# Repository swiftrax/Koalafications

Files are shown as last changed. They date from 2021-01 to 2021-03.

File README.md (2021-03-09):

# Koalafications
Built Image
75% Stacked Acrylic Keyboard with an OLED screen. QMK/VIA compatible 

## Hardware

* M3 Hex Spacer 10mm x 8
* M3 Hex Spacer 6mm x 3
* M3 Screw 8mm x 19
* M3 Screw 6mm x 3

## License

This repository is under the [CC0 1.0 Universal License](https://github.com/swiftrax/Nodu/blob/main/LICENSE). If you plan to sell these pcbs, make sure to read it.

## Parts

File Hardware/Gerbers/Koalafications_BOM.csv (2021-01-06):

value | footprint | datasheet | libsource/_lib | libsource/_part | libsource/_description | sheetpath/_names | sheetpath/_tstamps | tstamp | _ref | fields/field/0/_name | fields/field/0/__text
PRTR5V0U2X | Package_TO_SOT_SMD:SOT-143 | https://assets.nexperia.com/documents/data-sheet/PRTR5V0U2X.pdf | Power_Protection | PRTR5V0U2X | Ultra low capacitance double rail-to-rail ESD protection diode, SOT-363 | / | / | 5FDEC976 | ESD1
10µF | Custom_Footprints:C_0603_Annotated | ~ | Device | C_Small | Unpolarized capacitor, small symbol | / | / | 5FF1D678 | C1 | LCSC | C19702
100nF | Custom_Footprints:C_0603_Annotated | ~ | Device | C_Small | Unpolarized capacitor, small symbol | / | / | 5FF238E7 | C2 | LCSC | C14663
100nF | Custom_Footprints:C_0603_Annotated | ~ | Device | C_Small | Unpolarized capacitor, small symbol | / | / | 5FF29C94 | C3 | LCSC | C14663
100nF | Custom_Footprints:C_0603_Annotated | ~ | Device | C_Small | Unpolarized capacitor, small symbol | / | / | 5FF2FFA4 | C4 | LCSC | C14663
OLED | Custom_Footprints:SSD1306_OLED | ~ | Connector | Conn_01x04_Female | Generic connector, single row, 01x04, script generated (kicad-library-utils/schlib/autogen/connector/) | / | / | 600D2EB9 | J1
16MHz | Custom_Footprints:Resonator_3Pin_Annotated | ~ | Device | Resonator_Small | Three pin ceramic resonator, small symbol | / | / | 5FE6EE64 | Y1
RESET | Custom_Footprints:RESET_PADS | ~ | Switch | SW_Push | Push button switch, generic, two pins | / | / | 5FE7FCB3 | SW1
10kΩ | Custom_Footprints:R_0603_Annotated | ~ | Device | R_Small | Resistor, small symbol | / | / | 5FEDF25E | R2 | LCSC | C25804
10kΩ | Custom_Footprints:R_0603_Annotated | ~ | Device | R_Small | Resistor, small symbol | / | / | 5FEEABCC | R1 | LCSC | C25804
1µF | Custom_Footprints:C_0603_Annotated | ~ | Device | C_Small | Unpolarized capacitor, small symbol | / | / | 5FF0CD6B | C5 | LCSC | C15849
D_Small | Diode_SMD:D_0603_1608Metric_Pad1.05x0.95mm_HandSolder | ~ | Device | D_Small | Diode, small symbol | / | / | 5FF7E7FC | D82 | LCSC | C109002
KC_RGHT | MX_Only:MXOnly-1U-NoLED | ~ | Switch | SW_Push | Push button switch, generic, two pins | / | / | 5FF7E7F6 | K_82
D_Small | Diode_SMD:D_0603_1608Metric_Pad1.05x0.95mm_HandSolder | ~ | Device | D_Small | Diode, small symbol | / | / | 5FF7E7F0 | D72 | LCSC | C109002
KC_END | MX_Only:MXOnly-1U-NoLED | ~ | Switch | SW_Push | Push button switch, generic, two pins | / | / | 5FF7E7EA | K_72
D_Small | Diode_SMD:D_0603_1608Metric_Pad1.05x0.95mm_HandSolder | ~ | Device | D_Small | Diode, small symbol | / | / | 5FF7E7E4 | D58 | LCSC | C109002
KC_HOME | MX_Only:MXOnly-1U-NoLED | ~ | Switch | SW_Push | Push button switch, generic, two pins | / | / | 5FF7E7DE | K_58
D_Small | Diode_SMD:D_0603_1608Metric_Pad1.05x0.95mm_HandSolder | ~ | Device | D_Small | Diode, small symbol | / | / | 5FF7E7D8 | D43 | LCSC | C109002
KC_INS | MX_Only:MXOnly-1U-NoLED | ~ | Switch | SW_Push | Push button switch, generic, two pins | / | / | 5FF7E7D2 | K_43
D_Small | Diode_SMD:D_0603_1608Metric_Pad1.05x0.95mm_HandSolder | ~ | Device | D_Small | Diode, small symbol | / | / | 5FF7E7CC | D28 | LCSC | C109002
KC_DEL | MX_Only:MXOnly-1U-NoLED | ~ | Switch | SW_Push | Push button switch, generic, two pins | / | / | 5FF7E7C6 | K_28
D_Small | Diode_SMD:D_0603_1608Metric_Pad1.05x0.95mm_HandSolder | ~ | Device | D_Small | Diode, small symbol | / | / | 5FF7E78B | D57 | LCSC | C109002
KC_BSLS | MX_Only:MXOnly-1U-NoLED | ~ | Switch | SW_Push | Push button switch, generic, two pins | / | / | 5FF7E785 | K_57
D_Small | Diode_SMD:D_0603_1608Metric_Pad1.05x0.95mm_HandSolder | ~ | Device | D_Small | Diode, small symbol | / | / | 5FF7E77F | D42 | LCSC | C109002
KC_BSLS | MX_Only:MXOnly-1.5U-NoLED | ~ | Switch | SW_Push | Push button switch, generic, two pins | / | / | 5FF7E779 | K_42
D_Small | Diode_SMD:D_0603_1608Metric_Pad1.05x0.95mm_HandSolder | ~ | Device | D_Small | Diode, small symbol | / | / | 5FF7E773 | D27 | LCSC | C109002
KC_BSPC | MX_Only:MXOnly-2U-NoLED | ~ | Switch | SW_Push | Push button switch, generic, two pins | / | / | 5FF7E76D | K_27
D_Small | Diode_SMD:D_0603_1608Metric_Pad1.05x0.95mm_HandSolder | ~ | Device | D_Small | Diode, small symbol | / | / | 5FF63CA0 | D81 | LCSC | C109002
KC_DOWN | MX_Only:MXOnly-1U-NoLED | ~ | Switch | SW_Push | Push button switch, generic, two pins | / | / | 5FF63C9A | K_81
D_Small | Diode_SMD:D_0603_1608Metric_Pad1.05x0.95mm_HandSolder | ~ | Device | D_Small | Diode, small symbol | / | / | 5FF63C94 | D71 | LCSC | C109002
KC_UP | MX_Only:MXOnly-1U-NoLED | ~ | Switch | SW_Push | Push button switch, generic, two pins | / | / | 5FF63C8E | K_71
D_Small | Diode_SMD:D_0603_1608Metric_Pad1.05x0.95mm_HandSolder | ~ | Device | D_Small | Diode, small symbol | / | / | 5FF63C88 | D56 | LCSC | C109002
KC_ENT | MX_Only:MXOnly-2.25U-NoLED | ~ | Switch | SW_Push | Push button switch, generic, two pins | / | / | 5FF63C82 | K_56
D_Small | Diode_SMD:D_0603_1608Metric_Pad1.05x0.95mm_HandSolder | ~ | Device | D_Small | Diode, small symbol | / | / | 5FF63C7C | D41 | LCSC | C109002
KC_RBRC | MX_Only:MXOnly-1U-NoLED | ~ | Switch | SW_Push | Push button switch, generic, two pins | / | / | 5FF63C76 | K_41
D_Small | Diode_SMD:D_0603_1608Metric_Pad1.05x0.95mm_HandSolder | ~ | Device | D_Small | Diode, small symbol | / | / | 5FF63C70 | D26 | LCSC | C109002
KC_EQL | MX_Only:MXOnly-1U-NoLED | ~ | Switch | SW_Push | Push button switch, generic, two pins | / | / | 5FF63C6A | K_26
D_Small | Diode_SMD:D_0603_1608Metric_Pad1.05x0.95mm_HandSolder | ~ | Device | D_Small | Diode, small symbol | / | / | 5FF63C64 | D13 | LCSC | C109002
KC_F12 | MX_Only:MXOnly-1U-NoLED | ~ | Switch | SW_Push | Push button switch, generic, two pins | / | / | 5FF63C5E | K_13
D_Small | Diode_SMD:D_0603_1608Metric_Pad1.05x0.95mm_HandSolder | ~ | Device | D_Small | Diode, small symbol | / | / | 5FF63C47 | D80 | LCSC | C109002
KC_LEFT | MX_Only:MXOnly-1U-NoLED | ~ | Switch | SW_Push | Push button switch, generic, two pins | / | / | 5FF63C41 | K_80
D_Small | Diode_SMD:D_0603_1608Metric_Pad1.05x0.95mm_HandSolder | ~ | Device | D_Small | Diode, small symbol | / | / | 5FF63C3B | D70 | LCSC | C109002
KC_RSFT | MX_Only:MXOnly-1.75U-NoLED | ~ | Switch | SW_Push | Push button switch, generic, two pins | / | / | 5FF63C35 | K_70
D_Small | Diode_SMD:D_0603_1608Metric_Pad1.05x0.95mm_HandSolder | ~ | Device | D_Small | Diode, small symbol | / | / | 5FF63C2F | D55 | LCSC | C109002
KC_QUOT | MX_Only:MXOnly-1U-NoLED | ~ | Switch | SW_Push | Push button switch, generic, two pins | / | / | 5FF63C29 | K_55
D_Small | Diode_SMD:D_0603_1608Metric_Pad1.05x0.95mm_HandSolder | ~ | Device | D_Small | Diode, small symbol | / | / | 5FF63C23 | D40 | LCSC | C109002
KC_LBRC | MX_Only:MXOnly-1U-NoLED | ~ | Switch | SW_Push | Push button switch, generic, two pins | / | / | 5FF63C1D | K_40
D_Small | Diode_SMD:D_0603_1608Metric_Pad1.05x0.95mm_HandSolder | ~ | Device | D_Small | Diode, small symbol | / | / | 5FF63C17 | D25 | LCSC | C109002
KC_MINS | MX_Only:MXOnly-1U-NoLED | ~ | Switch | SW_Push | Push button switch, generic, two pins | / | / | 5FF63C11 | K_25
D_Small | Diode_SMD:D_0603_1608Metric_Pad1.05x0.95mm_HandSolder | ~ | Device | D_Small | Diode, small symbol | / | / | 5FF63C0B | D12 | LCSC | C109002
KC_F11 | MX_Only:MXOnly-1U-NoLED | ~ | Switch | SW_Push | Push button switch, generic, two pins | / | / | 5FF63C05 | K_12
D_Small | Diode_SMD:D_0603_1608Metric_Pad1.05x0.95mm_HandSolder | ~ | Device | D_Small | Diode, small symbol | / | / | 5FF63BEE | D79 | LCSC | C109002
KC_RCTL | MX_Only:MXOnly-1U-NoLED | ~ | Switch | SW_Push | Push button switch, generic, two pins | / | / | 5FF63BE8 | K_79
D_Small | Diode_SMD:D_0603_1608Metric_Pad1.05x0.95mm_HandSolder | ~ | Device | D_Small | Diode, small symbol | / | / | 5FF63BE2 | D69 | LCSC | C109002
KC_SLSH | MX_Only:MXOnly-1U-NoLED | ~ | Switch | SW_Push | Push button switch, generic, two pins | / | / | 5FF63BDC | K_69
D_Small | Diode_SMD:D_0603_1608Metric_Pad1.05x0.95mm_HandSolder | ~ | Device | D_Small | Diode, small symbol | / | / | 5FF63BD6 | D54 | LCSC | C109002
KC_SCLN | MX_Only:MXOnly-1U-NoLED | ~ | Switch | SW_Push | Push button switch, generic, two pins | / | / | 5FF63BD0 | K_54
D_Small | Diode_SMD:D_0603_1608Metric_Pad1.05x0.95mm_HandSolder | ~ | Device | D_Small | Diode, small symbol | / | / | 5FF63BCA | D39 | LCSC | C109002
KC_P | MX_Only:MXOnly-1U-NoLED | ~ | Switch | SW_Push | Push button switch, generic, two pins | / | / | 5FF63BC4 | K_39
D_Small | Diode_SMD:D_0603_1608Metric_Pad1.05x0.95mm_HandSolder | ~ | Device | D_Small | Diode, small symbol | / | / | 5FF63BBE | D24 | LCSC | C109002
KC_0 | MX_Only:MXOnly-1U-NoLED | ~ | Switch | SW_Push | Push button switch, generic, two pins | / | / | 5FF63BB8 | K_24
D_Small | Diode_SMD:D_0603_1608Metric_Pad1.05x0.95mm_HandSolder | ~ | Device | D_Small | Diode, small symbol | / | / | 5FF63BB2 | D11 | LCSC | C109002
KC_F10 | MX_Only:MXOnly-1U-NoLED | ~ | Switch | SW_Push | Push button switch, generic, two pins | / | / | 5FF63BAC | K_11
D_Small | Diode_SMD:D_0603_1608Metric_Pad1.05x0.95mm_HandSolder | ~ | Device | D_Small | Diode, small symbol | / | / | 5FF48720 | D78 | LCSC | C109002
KC_RGUI | MX_Only:MXOnly-1U-NoLED | ~ | Switch | SW_Push | Push button switch, generic, two pins | / | / | 5FF4871A | K_78
D_Small | Diode_SMD:D_0603_1608Metric_Pad1.05x0.95mm_HandSolder | ~ | Device | D_Small | Diode, small symbol | / | / | 5FF48714 | D68 | LCSC | C109002
KC_DOT | MX_Only:MXOnly-1U-NoLED | ~ | Switch | SW_Push | Push button switch, generic, two pins | / | / | 5FF4870E | K_68
D_Small | Diode_SMD:D_0603_1608Metric_Pad1.05x0.95mm_HandSolder | ~ | Device | D_Small | Diode, small symbol | / | / | 5FF48708 | D53 | LCSC | C109002
KC_L | MX_Only:MXOnly-1U-NoLED | ~ | Switch | SW_Push | Push button switch, generic, two pins | / | / | 5FF48702 | K_53
D_Small | Diode_SMD:D_0603_1608Metric_Pad1.05x0.95mm_HandSolder | ~ | Device | D_Small | Diode, small symbol | / | / | 5FF486FC | D38 | LCSC | C109002
KC_O | MX_Only:MXOnly-1U-NoLED | ~ | Switch | SW_Push | Push button switch, generic, two pins | / | / | 5FF486F6 | K_38
D_Small | Diode_SMD:D_0603_1608Metric_Pad1.05x0.95mm_HandSolder | ~ | Device | D_Small | Diode, small symbol | / | / | 5FF486F0 | D23 | LCSC | C109002
KC_9 | MX_Only:MXOnly-1U-NoLED | ~ | Switch | SW_Push | Push button switch, generic, two pins | / | / | 5FF486EA | K_23
D_Small | Diode_SMD:D_0603_1608Metric_Pad1.05x0.95mm_HandSolder | ~ | Device | D_Small | Diode, small symbol | / | / | 5FF486E4 | D10 | LCSC | C109002
KC_F9 | MX_Only:MXOnly-1U-NoLED | ~ | Switch | SW_Push | Push button switch, generic, two pins | / | / | 5FF486DE | K_10
D_Small | Diode_SMD:D_0603_1608Metric_Pad1.05x0.95mm_HandSolder | ~ | Device | D_Small | Diode, small symbol | / | / | 5FF486C7 | D77 | LCSC | C109002
KC_RALT | MX_Only:MXOnly-1U-NoLED | ~ | Switch | SW_Push | Push button switch, generic, two pins | / | / | 5FF486C1 | K_77
D_Small | Diode_SMD:D_0603_1608Metric_Pad1.05x0.95mm_HandSolder | ~ | Device | D_Small | Diode, small symbol | / | / | 5FF486BB | D67 | LCSC | C109002
KC_COMM | MX_Only:MXOnly-1U-NoLED | ~ | Switch | SW_Push | Push button switch, generic, two pins | / | / | 5FF486B5 | K_67
D_Small | Diode_SMD:D_0603_1608Metric_Pad1.05x0.95mm_HandSolder | ~ | Device | D_Small | Diode, small symbol | / | / | 5FF486AF | D52 | LCSC | C109002
KC_K | MX_Only:MXOnly-1U-NoLED | ~ | Switch | SW_Push | Push button switch, generic, two pins | / | / | 5FF486A9 | K_52
D_Small | Diode_SMD:D_0603_1608Metric_Pad1.05x0.95mm_HandSolder | ~ | Device | D_Small | Diode, small symbol | / | / | 5FF486A3 | D37 | LCSC | C109002
KC_I | MX_Only:MXOnly-1U-NoLED | ~ | Switch | SW_Push | Push button switch, generic, two pins | / | / | 5FF4869D | K_37
D_Small | Diode_SMD:D_0603_1608Metric_Pad1.05x0.95mm_HandSolder | ~ | Device | D_Small | Diode, small symbol | / | / | 5FF48697 | D22 | LCSC | C109002
KC_8 | MX_Only:MXOnly-1U-NoLED | ~ | Switch | SW_Push | Push button switch, generic, two pins | / | / | 5FF48691 | K_22
D_Small | Diode_SMD:D_0603_1608Metric_Pad1.05x0.95mm_HandSolder | ~ | Device | D_Small | Diode, small symbol | / | / | 5FF4868B | D9 | LCSC | C109002
KC_F8 | MX_Only:MXOnly-1U-NoLED | ~ | Switch | SW_Push | Push button switch, generic, two pins | / | / | 5FF48685 | K_9
D_Small | Diode_SMD:D_0603_1608Metric_Pad1.05x0.95mm_HandSolder | ~ | Device | D_Small | Diode, small symbol | / | / | 5FF48662 | D66 | LCSC | C109002
KC_M | MX_Only:MXOnly-1U-NoLED | ~ | Switch | SW_Push | Push button switch, generic, two pins | / | / | 5FF4865C | K_66
D_Small | Diode_SMD:D_0603_1608Metric_Pad1.05x0.95mm_HandSolder | ~ | Device | D_Small | Diode, small symbol | / | / | 5FF48656 | D51 | LCSC | C109002
KC_J | MX_Only:MXOnly-1U-NoLED | ~ | Switch | SW_Push | Push button switch, generic, two pins | / | / | 5FF48650 | K_51
D_Small | Diode_SMD:D_0603_1608Metric_Pad1.05x0.95mm_HandSolder | ~ | Device | D_Small | Diode, small symbol | / | / | 5FF4864A | D36 | LCSC | C109002
KC_U | MX_Only:MXOnly-1U-NoLED | ~ | Switch | SW_Push | Push button switch, generic, two pins | / | / | 5FF48644 | K_36
D_Small | Diode_SMD:D_0603_1608Metric_Pad1.05x0.95mm_HandSolder | ~ | Device | D_Small | Diode, small symbol | / | / | 5FF4863E | D21 | LCSC | C109002
KC_7 | MX_Only:MXOnly-1U-NoLED | ~ | Switch | SW_Push | Push button switch, generic, two pins | / | / | 5FF48638 | K_21
D_Small | Diode_SMD:D_0603_1608Metric_Pad1.05x0.95mm_HandSolder | ~ | Device | D_Small | Diode, small symbol | / | / | 5FF48632 | D8 | LCSC | C109002
KC_F7 | MX_Only:MXOnly-1U-NoLED | ~ | Switch | SW_Push | Push button switch, generic, two pins | / | / | 5FF4862C | K_8
D_Small | Diode_SMD:D_0603_1608Metric_Pad1.05x0.95mm_HandSolder | ~ | Device | D_Small | Diode, small symbol | / | / | 5FF2F869 | D76 | LCSC | C109002
KC_SPC | MX_Only:MXOnly-6.25U-ReversedStabilizers-NoLED | ~ | Switch | SW_Push | Push button switch, generic, two pins | / | / | 5FF2F863 | K_76
D_Small | Diode_SMD:D_0603_1608Metric_Pad1.05x0.95mm_HandSolder | ~ | Device | D_Small | Diode, small symbol | / | / | 5FF2F85D | D65 | LCSC | C109002
KC_N | MX_Only:MXOnly-1U-NoLED | ~ | Switch | SW_Push | Push button switch, generic, two pins | / | / | 5FF2F857 | K_65
D_Small | Diode_SMD:D_0603_1608Metric_Pad1.05x0.95mm_HandSolder | ~ | Device | D_Small | Diode, small symbol | / | / | 5FF2F851 | D50 | LCSC | C109002
KC_H | MX_Only:MXOnly-1U-NoLED | ~ | Switch | SW_Push | Push button switch, generic, two pins | / | / | 5FF2F84B | K_50
D_Small | Diode_SMD:D_0603_1608Metric_Pad1.05x0.95mm_HandSolder | ~ | Device | D_Small | Diode, small symbol | / | / | 5FF2F845 | D35 | LCSC | C109002
KC_Y | MX_Only:MXOnly-1U-NoLED | ~ | Switch | SW_Push | Push button switch, generic, two pins | / | / | 5FF2F83F | K_35
D_Small | Diode_SMD:D_0603_1608Metric_Pad1.05x0.95mm_HandSolder | ~ | Device | D_Small | Diode, small symbol | / | / | 5FF2F839 | D20 | LCSC | C109002
KC_6 | MX_Only:MXOnly-1U-NoLED | ~ | Switch | SW_Push | Push button switch, generic, two pins | / | / | 5FF2F833 | K_20
D_Small | Diode_SMD:D_0603_1608Metric_Pad1.05x0.95mm_HandSolder | ~ | Device | D_Small | Diode, small symbol | / | / | 5FF2F82D | D7 | LCSC | C109002
KC_F6 | MX_Only:MXOnly-1U-NoLED | ~ | Switch | SW_Push | Push button switch, generic, two pins | / | / | 5FF2F827 | K_7
D_Small | Diode_SMD:D_0603_1608Metric_Pad1.05x0.95mm_HandSolder | ~ | Device | D_Small | Diode, small symbol | / | / | 5FF2F804 | D64 | LCSC | C109002
KC_B | MX_Only:MXOnly-1U-NoLED | ~ | Switch | SW_Push | Push button switch, generic, two pins | / | / | 5FF2F7FE | K_64
D_Small | Diode_SMD:D_0603_1608Metric_Pad1.05x0.95mm_HandSolder | ~ | Device | D_Small | Diode, small symbol | / | / | 5FF2F7F8 | D49 | LCSC | C109002
KC_G | MX_Only:MXOnly-1U-NoLED | ~ | Switch | SW_Push | Push button switch, generic, two pins | / | / | 5FF2F7F2 | K_49
D_Small | Diode_SMD:D_0603_1608Metric_Pad1.05x0.95mm_HandSolder | ~ | Device | D_Small | Diode, small symbol | / | / | 5FF2F7EC | D34 | LCSC | C109002
KC_T | MX_Only:MXOnly-1U-NoLED | ~ | Switch | SW_Push | Push button switch, generic, two pins | / | / | 5FF2F7E6 | K_34
D_Small | Diode_SMD:D_0603_1608Metric_Pad1.05x0.95mm_HandSolder | ~ | Device | D_Small | Diode, small symbol | / | / | 5FF2F7E0 | D19 | LCSC | C109002
KC_5 | MX_Only:MXOnly-1U-NoLED | ~ | Switch | SW_Push | Push button switch, generic, two pins | / | / | 5FF2F7DA | K_19
D_Small | Diode_SMD:D_0603_1608Metric_Pad1.05x0.95mm_HandSolder | ~ | Device | D_Small | Diode, small symbol | / | / | 5FF2F7D4 | D6 | LCSC | C109002
KC_F5 | MX_Only:MXOnly-1U-NoLED | ~ | Switch | SW_Push | Push button switch, generic, two pins | / | / | 5FF2F7CE | K_6
D_Small | Diode_SMD:D_0603_1608Metric_Pad1.05x0.95mm_HandSolder | ~ | Device | D_Small | Diode, small symbol | / | / | 5FF2F7AB | D63 | LCSC | C109002
KC_V | MX_Only:MXOnly-1U-NoLED | ~ | Switch | SW_Push | Push button switch, generic, two pins | / | / | 5FF2F7A5 | K_63
D_Small | Diode_SMD:D_0603_1608Metric_Pad1.05x0.95mm_HandSolder | ~ | Device | D_Small | Diode, small symbol | / | / | 5FF2F79F | D48 | LCSC | C109002
KC_F | MX_Only:MXOnly-1U-NoLED | ~ | Switch | SW_Push | Push button switch, generic, two pins | / | / | 5FF2F799 | K_48
D_Small | Diode_SMD:D_0603_1608Metric_Pad1.05x0.95mm_HandSolder | ~ | Device | D_Small | Diode, small symbol | / | / | 5FF2F793 | D33 | LCSC | C109002
KC_R | MX_Only:MXOnly-1U-NoLED | ~ | Switch | SW_Push | Push button switch, generic, two pins | / | / | 5FF2F78D | K_33
D_Small | Diode_SMD:D_0603_1608Metric_Pad1.05x0.95mm_HandSolder | ~ | Device | D_Small | Diode, small symbol | / | / | 5FF2F787 | D18 | LCSC | C109002
KC_4 | MX_Only:MXOnly-1U-NoLED | ~ | Switch | SW_Push | Push button switch, generic, two pins | / | / | 5FF2F781 | K_18
D_Small | Diode_SMD:D_0603_1608Metric_Pad1.05x0.95mm_HandSolder | ~ | Device | D_Small | Diode, small symbol | / | / | 5FF2F77B | D5 | LCSC | C109002
KC_F4 | MX_Only:MXOnly-1U-NoLED | ~ | Switch | SW_Push | Push button switch, generic, two pins | / | / | 5FF2F775 | K_5
D_Small | Diode_SMD:D_0603_1608Metric_Pad1.05x0.95mm_HandSolder | ~ | Device | D_Small | Diode, small symbol | / | / | 5FF17EE4 | D62 | LCSC | C109002
KC_C | MX_Only:MXOnly-1U-NoLED | ~ | Switch | SW_Push | Push button switch, generic, two pins | / | / | 5FF17EDE | K_62
D_Small | Diode_SMD:D_0603_1608Metric_Pad1.05x0.95mm_HandSolder | ~ | Device | D_Small | Diode, small symbol | / | / | 5FF17ED8 | D47 | LCSC | C109002
KC_D | MX_Only:MXOnly-1U-NoLED | ~ | Switch | SW_Push | Push button switch, generic, two pins | / | / | 5FF17ED2 | K_47
D_Small | Diode_SMD:D_0603_1608Metric_Pad1.05x0.95mm_HandSolder | ~ | Device | D_Small | Diode, small symbol | / | / | 5FF17ECC | D32 | LCSC | C109002
KC_E | MX_Only:MXOnly-1U-NoLED | ~ | Switch | SW_Push | Push button switch, generic, two pins | / | / | 5FF17EC6 | K_32
D_Small | Diode_SMD:D_0603_1608Metric_Pad1.05x0.95mm_HandSolder | ~ | Device | D_Small | Diode, small symbol | / | / | 5FF17EC0 | D17 | LCSC | C109002
KC_3 | MX_Only:MXOnly-1U-NoLED | ~ | Switch | SW_Push | Push button switch, generic, two pins | / | / | 5FF17EBA | K_17
D_Small | Diode_SMD:D_0603_1608Metric_Pad1.05x0.95mm_HandSolder | ~ | Device | D_Small | Diode, small symbol | / | / | 5FF17EB4 | D4 | LCSC | C109002
KC_F3 | MX_Only:MXOnly-1U-NoLED | ~ | Switch | SW_Push | Push button switch, generic, two pins | / | / | 5FF17EAE | K_4
D_Small | Diode_SMD:D_0603_1608Metric_Pad1.05x0.95mm_HandSolder | ~ | Device | D_Small | Diode, small symbol | / | / | 5FF11209 | D75 | LCSC | C109002
KC_LALT | MX_Only:MXOnly-1.25U-NoLED | ~ | Switch | SW_Push | Push button switch, generic, two pins | / | / | 5FF11203 | K_75
D_Small | Diode_SMD:D_0603_1608Metric_Pad1.05x0.95mm_HandSolder | ~ | Device | D_Small | Diode, small symbol | / | / | 5FF111FD | D61 | LCSC | C109002
KC_X | MX_Only:MXOnly-1U-NoLED | ~ | Switch | SW_Push | Push button switch, generic, two pins | / | / | 5FF111F7 | K_61
D_Small | Diode_SMD:D_0603_1608Metric_Pad1.05x0.95mm_HandSolder | ~ | Device | D_Small | Diode, small symbol | / | / | 5FF111F1 | D46 | LCSC | C109002
KC_S | MX_Only:MXOnly-1U-NoLED | ~ | Switch | SW_Push | Push button switch, generic, two pins | / | / | 5FF111EB | K_46
D_Small | Diode_SMD:D_0603_1608Metric_Pad1.05x0.95mm_HandSolder | ~ | Device | D_Small | Diode, small symbol | / | / | 5FF111E5 | D31 | LCSC | C109002
KC_W | MX_Only:MXOnly-1U-NoLED | ~ | Switch | SW_Push | Push button switch, generic, two pins | / | / | 5FF111DF | K_31
D_Small | Diode_SMD:D_0603_1608Metric_Pad1.05x0.95mm_HandSolder | ~ | Device | D_Small | Diode, small symbol | / | / | 5FF111D9 | D16 | LCSC | C109002
KC_2 | MX_Only:MXOnly-1U-NoLED | ~ | Switch | SW_Push | Push button switch, generic, two pins | / | / | 5FF111D3 | K_16
D_Small | Diode_SMD:D_0603_1608Metric_Pad1.05x0.95mm_HandSolder | ~ | Device | D_Small | Diode, small symbol | / | / | 5FF111CD | D3 | LCSC | C109002
KC_F2 | MX_Only:MXOnly-1U-NoLED | ~ | Switch | SW_Push | Push button switch, generic, two pins | / | / | 5FF111C7 | K_3
D_Small | Diode_SMD:D_0603_1608Metric_Pad1.05x0.95mm_HandSolder | ~ | Device | D_Small | Diode, small symbol | / | / | 5FEF051F | D74 | LCSC | C109002
KC_LGUI | MX_Only:MXOnly-1.25U-NoLED | ~ | Switch | SW_Push | Push button switch, generic, two pins | / | / | 5FEF0519 | K_74
D_Small | Diode_SMD:D_0603_1608Metric_Pad1.05x0.95mm_HandSolder | ~ | Device | D_Small | Diode, small symbol | / | / | 5FEF0513 | D60 | LCSC | C109002
KC_Z | MX_Only:MXOnly-1U-NoLED | ~ | Switch | SW_Push | Push button switch, generic, two pins | / | / | 5FEF050D | K_60
D_Small | Diode_SMD:D_0603_1608Metric_Pad1.05x0.95mm_HandSolder | ~ | Device | D_Small | Diode, small symbol | / | / | 5FEF0507 | D45 | LCSC | C109002
KC_A | MX_Only:MXOnly-1U-NoLED | ~ | Switch | SW_Push | Push button switch, generic, two pins | / | / | 5FEF0501 | K_45
D_Small | Diode_SMD:D_0603_1608Metric_Pad1.05x0.95mm_HandSolder | ~ | Device | D_Small | Diode, small symbol | / | / | 5FEF04FB | D30 | LCSC | C109002
KC_Q | MX_Only:MXOnly-1U-NoLED | ~ | Switch | SW_Push | Push button switch, generic, two pins | / | / | 5FEF04F5 | K_30
D_Small | Diode_SMD:D_0603_1608Metric_Pad1.05x0.95mm_HandSolder | ~ | Device | D_Small | Diode, small symbol | / | / | 5FEF04EF | D15 | LCSC | C109002
KC_1 | MX_Only:MXOnly-1U-NoLED | ~ | Switch | SW_Push | Push button switch, generic, two pins | / | / | 5FEF04E9 | K_15
D_Small | Diode_SMD:D_0603_1608Metric_Pad1.05x0.95mm_HandSolder | ~ | Device | D_Small | Diode, small symbol | / | / | 5FEF04E3 | D2 | LCSC | C109002
KC_F1 | MX_Only:MXOnly-1U-NoLED | ~ | Switch | SW_Push | Push button switch, generic, two pins | / | / | 5FEF04DD | K_2
D_Small | Diode_SMD:D_0603_1608Metric_Pad1.05x0.95mm_HandSolder | ~ | Device | D_Small | Diode, small symbol | / | / | 5FEEDEF3 | D73 | LCSC | C109002
KC_LCTL | MX_Only:MXOnly-1.25U-NoLED | ~ | Switch | SW_Push | Push button switch, generic, two pins | / | / | 5FEEDEED | K_73
D_Small | Diode_SMD:D_0603_1608Metric_Pad1.05x0.95mm_HandSolder | ~ | Device | D_Small | Diode, small symbol | / | / | 5FEEDEE7 | D59 | LCSC | C109002
KC_LSFT | MX_Only:MXOnly-2.25U-NoLED | ~ | Switch | SW_Push | Push button switch, generic, two pins | / | / | 5FEEDEE1 | K_59
D_Small | Diode_SMD:D_0603_1608Metric_Pad1.05x0.95mm_HandSolder | ~ | Device | D_Small | Diode, small symbol | / | / | 5FEEA1C1 | D44 | LCSC | C109002
KC_CAPS | MX_Only:MXOnly-1.75U-NoLED | ~ | Switch | SW_Push | Push button switch, generic, two pins | / | / | 5FEEA1BB | K_44
D_Small | Diode_SMD:D_0603_1608Metric_Pad1.05x0.95mm_HandSolder | ~ | Device | D_Small | Diode, small symbol | / | / | 5FEEA1B5 | D29 | LCSC | C109002
KC_TAB | MX_Only:MXOnly-1.5U-NoLED | ~ | Switch | SW_Push | Push button switch, generic, two pins | / | / | 5FEEA1AF | K_29
D_Small | Diode_SMD:D_0603_1608Metric_Pad1.05x0.95mm_HandSolder | ~ | Device | D_Small | Diode, small symbol | / | / | 5FEE4945 | D14 | LCSC | C109002
KC_GRV | MX_Only:MXOnly-1U-NoLED | ~ | Switch | SW_Push | Push button switch, generic, two pins | / | / | 5FEE493F | K_14
D_Small | Diode_SMD:D_0603_1608Metric_Pad1.05x0.95mm_HandSolder | ~ | Device | D_Small | Diode, small symbol | / | / | 5FEDF2C4 | D1 | LCSC | C109002
KC_ESC | MX_Only:MXOnly-1U-NoLED | ~ | Switch | SW_Push | Push button switch, generic, two pins | / | / | 5FEDE563 | K_1
HRO-TYPE-C-31-M-12 | Type-C:HRO-TYPE-C-31-M-12 |  | Type-C | HRO-TYPE-C-31-M-12 |  | / | / | 5FD590CA | USB1
5.1kΩ | Custom_Footprints:R_0603_Annotated | ~ | Device | R_Small | Resistor, small symbol | / | / | 5FD7141F | R5 | LCSC | C23186
5.1kΩ | Custom_Footprints:R_0603_Annotated | ~ | Device | R_Small | Resistor, small symbol | / | / | 5FD72FFC | R6 | LCSC | C23186
22Ω | Custom_Footprints:R_0603_Annotated | ~ | Device | R_Small | Resistor, small symbol | / | / | 5FD7E017 | R4 | LCSC | C23345
22Ω | Custom_Footprints:R_0603_Annotated | ~ | Device | R_Small | Resistor, small symbol | / | / | 5FD81472 | R3 | LCSC | C23345
500mA | Custom_Footprints:Fuse_1206_Annotated | ~ | Device | Polyfuse_Small | Resettable fuse, polymeric positive temperature coefficient, small symbol | / | / | 5FDD8A49 | F1
KC_ | MX_Only:MXOnly-1.5U-NoLED | ~ | Switch | SW_Push | Push button switch, generic, two pins | / | / | 5FF43758 | K_508A1
KC_RCTL | MX_Only:MXOnly-1.5U-NoLED | ~ | Switch | SW_Push | Push button switch, generic, two pins | / | / | 5FF73369 | K_510A1
KC_CAPS | MX_Only:MXOnly-1.25U-NoLED | ~ | Switch | SW_Push | Push button switch, generic, two pins | / | / | 5FFB3E52 | K_300A1
KC_BSPC | MX_Only:MXOnly-1U-NoLED | ~ | Switch | SW_Push | Push button switch, generic, two pins | / | / | 5FFE6364 | K_113A1
ATmega32U4-MU | Package_DFN_QFN:QFN-44-1EP_7x7mm_P0.5mm_EP5.2x5.2mm | http://ww1.microchip.com/downloads/en/DeviceDoc/Atmel-7766-8-bit-AVR-ATmega16U4-32U4_Datasheet.pdf | MCU_Microchip_ATmega | ATmega32U4-MU | 16MHz, 32kB Flash, 2.5kB SRAM, 1kB EEPROM, USB 2.0, QFN-44 | / | / | 600A56EF | U1 | LCSC | C45874

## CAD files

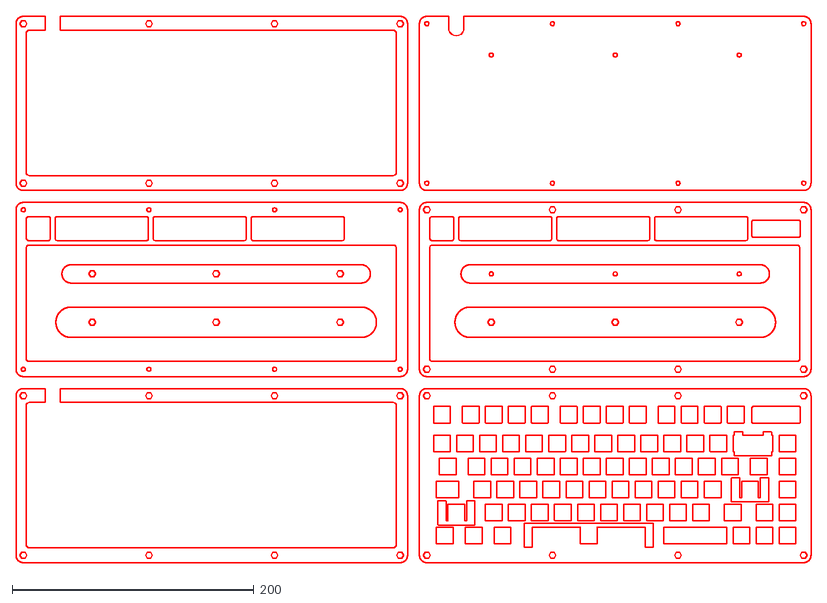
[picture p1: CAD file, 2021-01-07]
Laser Files/Koalafications.dxf
657.4 x 451.8

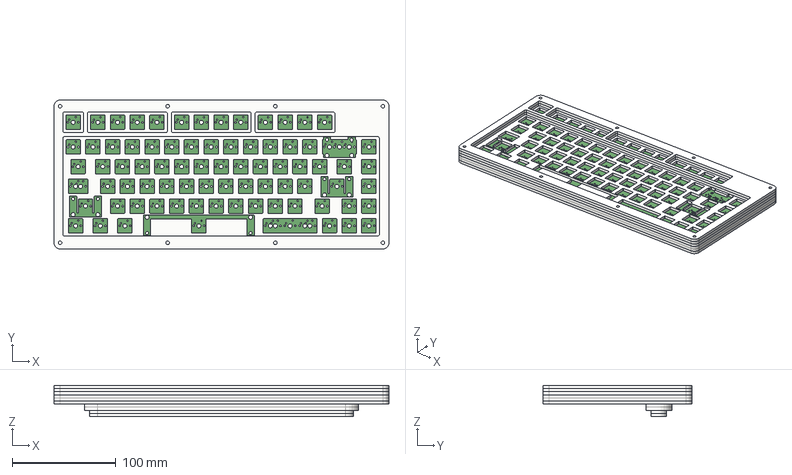
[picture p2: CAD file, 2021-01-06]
Laser Files/Koalafications_Stacked_Acrylic_Case.step
323.7 x 143.9 x 30.0 mm
Plate
Top_1
Top_2
Mid
Mid (1)
Bottom
Foot
Foot (1)
Foot (2)
Foot (3)

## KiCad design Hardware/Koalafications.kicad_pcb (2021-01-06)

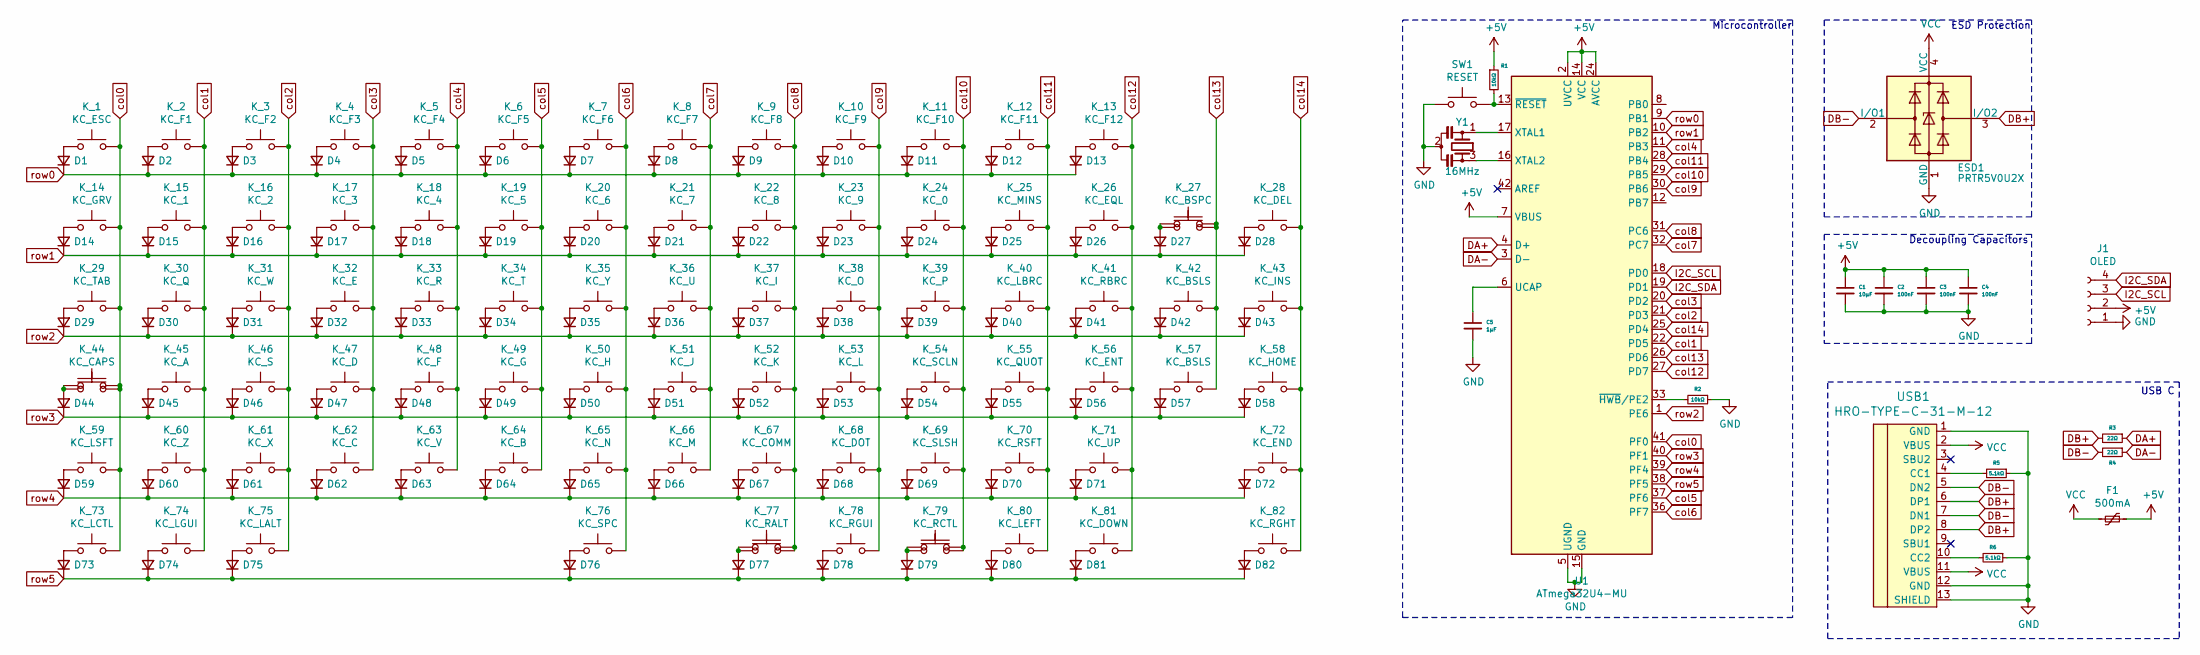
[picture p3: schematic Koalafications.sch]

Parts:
C1: 10µF; C_0603_Annotated; LCSC C19702
C2, C3, C4: 100nF; C_0603_Annotated; LCSC C14663
C5: 1µF; C_0603_Annotated; LCSC C15849
D1, D2, D3, D4, D5, D6, D7, D8, D9, D10, D11, D12, D13, D14, D15, D16, D17, D18, D19, D20, D21, D22, D23, D24, D25, D26, D27, D28, D29, D30, D31, D32, D33, D34, D35, D36, D37, D38, D39, D40, D41, D42, D43, D44, D45, D46, D47, D48, D49, D50, D51, D52, D53, D54, D55, D56, D57, D58, D59, D60, D61, D62, D63, D64, D65, D66, D67, D68, D69, D70, D71, D72, D73, D74, D75, D76, D77, D78, D79, D80, D81, D82: D_Small; D_0603_1608Metric_Pad1.05x0.95mm_HandSolder; LCSC C109002
ESD1: PRTR5V0U2X; SOT-143
F1: 500mA; Fuse_1206_Annotated
J1: OLED; SSD1306_OLED
K_1: KC_ESC; MXOnly-1U-NoLED
K_2: KC_F1; MXOnly-1U-NoLED
K_3: KC_F2; MXOnly-1U-NoLED
K_4: KC_F3; MXOnly-1U-NoLED
K_5: KC_F4; MXOnly-1U-NoLED
K_6: KC_F5; MXOnly-1U-NoLED
K_7: KC_F6; MXOnly-1U-NoLED
K_8: KC_F7; MXOnly-1U-NoLED
K_9: KC_F8; MXOnly-1U-NoLED
K_10: KC_F9; MXOnly-1U-NoLED
K_11: KC_F10; MXOnly-1U-NoLED
K_12: KC_F11; MXOnly-1U-NoLED
K_13: KC_F12; MXOnly-1U-NoLED
K_14: KC_GRV; MXOnly-1U-NoLED
K_15: KC_1; MXOnly-1U-NoLED
K_16: KC_2; MXOnly-1U-NoLED
K_17: KC_3; MXOnly-1U-NoLED
K_18: KC_4; MXOnly-1U-NoLED
K_19: KC_5; MXOnly-1U-NoLED
K_20: KC_6; MXOnly-1U-NoLED
K_21: KC_7; MXOnly-1U-NoLED
K_22: KC_8; MXOnly-1U-NoLED
K_23: KC_9; MXOnly-1U-NoLED
K_24: KC_0; MXOnly-1U-NoLED
K_25: KC_MINS; MXOnly-1U-NoLED
K_26: KC_EQL; MXOnly-1U-NoLED
K_27: KC_BSPC; MXOnly-2U-NoLED
K_28: KC_DEL; MXOnly-1U-NoLED
K_29: KC_TAB; MXOnly-1.5U-NoLED
K_30: KC_Q; MXOnly-1U-NoLED
K_31: KC_W; MXOnly-1U-NoLED
K_32: KC_E; MXOnly-1U-NoLED
K_33: KC_R; MXOnly-1U-NoLED
K_34: KC_T; MXOnly-1U-NoLED
K_35: KC_Y; MXOnly-1U-NoLED
K_36: KC_U; MXOnly-1U-NoLED
K_37: KC_I; MXOnly-1U-NoLED
K_38: KC_O; MXOnly-1U-NoLED
K_39: KC_P; MXOnly-1U-NoLED
K_40: KC_LBRC; MXOnly-1U-NoLED
K_41: KC_RBRC; MXOnly-1U-NoLED
K_42: KC_BSLS; MXOnly-1.5U-NoLED
K_43: KC_INS; MXOnly-1U-NoLED
K_44: KC_CAPS; MXOnly-1.75U-NoLED
K_45: KC_A; MXOnly-1U-NoLED
K_46: KC_S; MXOnly-1U-NoLED
K_47: KC_D; MXOnly-1U-NoLED
K_48: KC_F; MXOnly-1U-NoLED
K_49: KC_G; MXOnly-1U-NoLED
K_50: KC_H; MXOnly-1U-NoLED
K_51: KC_J; MXOnly-1U-NoLED
K_52: KC_K; MXOnly-1U-NoLED
K_53: KC_L; MXOnly-1U-NoLED
K_54: KC_SCLN; MXOnly-1U-NoLED
K_55: KC_QUOT; MXOnly-1U-NoLED
K_56: KC_ENT; MXOnly-2.25U-NoLED
K_57: KC_BSLS; MXOnly-1U-NoLED
K_58: KC_HOME; MXOnly-1U-NoLED
K_59: KC_LSFT; MXOnly-2.25U-NoLED
K_60: KC_Z; MXOnly-1U-NoLED
K_61: KC_X; MXOnly-1U-NoLED
K_62: KC_C; MXOnly-1U-NoLED
K_63: KC_V; MXOnly-1U-NoLED
K_64: KC_B; MXOnly-1U-NoLED
K_65: KC_N; MXOnly-1U-NoLED
K_66: KC_M; MXOnly-1U-NoLED
K_67: KC_COMM; MXOnly-1U-NoLED
K_68: KC_DOT; MXOnly-1U-NoLED
K_69: KC_SLSH; MXOnly-1U-NoLED
K_70: KC_RSFT; MXOnly-1.75U-NoLED
K_71: KC_UP; MXOnly-1U-NoLED
K_72: KC_END; MXOnly-1U-NoLED
K_73: KC_LCTL; MXOnly-1.25U-NoLED
K_74: KC_LGUI; MXOnly-1.25U-NoLED
K_75: KC_LALT; MXOnly-1.25U-NoLED
K_76: KC_SPC; MXOnly-6.25U-ReversedStabilizers-NoLED
K_77: KC_RALT; MXOnly-1U-NoLED
K_78: KC_RGUI; MXOnly-1U-NoLED
K_79: KC_RCTL; MXOnly-1U-NoLED
K_80: KC_LEFT; MXOnly-1U-NoLED
K_81: KC_DOWN; MXOnly-1U-NoLED
K_82: KC_RGHT; MXOnly-1U-NoLED
K_113A1: KC_BSPC; MXOnly-1U-NoLED
K_300A1: KC_CAPS; MXOnly-1.25U-NoLED
K_508A1: KC_; MXOnly-1.5U-NoLED
K_510A1: KC_RCTL; MXOnly-1.5U-NoLED
R1, R2: 10kΩ; R_0603_Annotated; LCSC C25804
R3, R4: 22Ω; R_0603_Annotated; LCSC C23345
R5, R6: 5.1kΩ; R_0603_Annotated; LCSC C23186
SW1: RESET; RESET_PADS
U1: ATmega32U4-MU; QFN-44-1EP_7x7mm_P0.5mm_EP5.2x5.2mm; LCSC C45874
USB1: HRO-TYPE-C-31-M-12
Y1: 16MHz; Resonator_3Pin_Annotated

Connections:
+5V: C1.1, C2.1, C3.1, C4.1, F1.1, J1.2, R1.1, U1.2 (UVCC), U1.7 (VBUS), U1.14 (VCC), U1.24 (AVCC), U1.34 (VCC), U1.44 (AVCC)
DA+: R3.1, U1.4 (D+)
DA-: R4.1, U1.3 (D-)
DB+: ESD1.3 (I/O2), R3.2, USB1.6 (DP1), USB1.8 (DP2)
DB-: ESD1.2 (I/O1), R4.2, USB1.5 (DN2), USB1.7 (DN1)
GND: C1.2, C2.2, C3.2, C4.2, C5.2, ESD1.1 (GND), J1.1, R2.1, R5.1, R6.1, SW1.1, U1.5 (UGND), U1.15 (GND), U1.23 (GND), U1.35 (GND), U1.43 (GND), U1.45 (GND), USB1.1 (GND), USB1.12 (GND), USB1.13 (SHIELD), Y1.2
I2C_SCL: J1.3, U1.18 (PD0)
I2C_SDA: J1.4, U1.19 (PD1)
unnamed: C5.1, U1.6 (UCAP)
unnamed: D1.2 (A), K_1.1
unnamed: D2.2 (A), K_2.1
unnamed: D3.2 (A), K_3.1
unnamed: D4.2 (A), K_4.1
unnamed: D5.2 (A), K_5.1
unnamed: D6.2 (A), K_6.1
unnamed: D7.2 (A), K_7.1
unnamed: D8.2 (A), K_8.1
unnamed: D9.2 (A), K_9.1
unnamed: D10.2 (A), K_10.1
unnamed: D11.2 (A), K_11.1
unnamed: D12.2 (A), K_12.1
unnamed: D13.2 (A), K_13.1
unnamed: D14.2 (A), K_14.1
unnamed: D15.2 (A), K_15.1
unnamed: D16.2 (A), K_16.1
unnamed: D17.2 (A), K_17.1
unnamed: D18.2 (A), K_18.1
unnamed: D19.2 (A), K_19.1
unnamed: D20.2 (A), K_20.1
unnamed: D21.2 (A), K_21.1
unnamed: D22.2 (A), K_22.1
unnamed: D23.2 (A), K_23.1
unnamed: D24.2 (A), K_24.1
unnamed: D25.2 (A), K_25.1
unnamed: D26.2 (A), K_26.1
unnamed: D27.2 (A), K_27.1, K_113A1.1
unnamed: D28.2 (A), K_28.1
unnamed: D29.2 (A), K_29.1
unnamed: D30.2 (A), K_30.1
unnamed: D31.2 (A), K_31.1
unnamed: D32.2 (A), K_32.1
unnamed: D33.2 (A), K_33.1
unnamed: D34.2 (A), K_34.1
unnamed: D35.2 (A), K_35.1
unnamed: D36.2 (A), K_36.1
unnamed: D37.2 (A), K_37.1
unnamed: D38.2 (A), K_38.1
unnamed: D39.2 (A), K_39.1
unnamed: D40.2 (A), K_40.1
unnamed: D41.2 (A), K_41.1
unnamed: D42.2 (A), K_42.1
unnamed: D43.2 (A), K_43.1
unnamed: D44.2 (A), K_44.1, K_300A1.1
unnamed: D45.2 (A), K_45.1
unnamed: D46.2 (A), K_46.1
unnamed: D47.2 (A), K_47.1
unnamed: D48.2 (A), K_48.1
unnamed: D49.2 (A), K_49.1
unnamed: D50.2 (A), K_50.1
unnamed: D51.2 (A), K_51.1
unnamed: D52.2 (A), K_52.1
unnamed: D53.2 (A), K_53.1
unnamed: D54.2 (A), K_54.1
unnamed: D55.2 (A), K_55.1
unnamed: D56.2 (A), K_56.1
unnamed: D57.2 (A), K_57.1
unnamed: D58.2 (A), K_58.1
unnamed: D59.2 (A), K_59.1
unnamed: D60.2 (A), K_60.1
unnamed: D61.2 (A), K_61.1
unnamed: D62.2 (A), K_62.1
unnamed: D63.2 (A), K_63.1
unnamed: D64.2 (A), K_64.1
unnamed: D65.2 (A), K_65.1
unnamed: D66.2 (A), K_66.1
unnamed: D67.2 (A), K_67.1
unnamed: D68.2 (A), K_68.1
unnamed: D69.2 (A), K_69.1
unnamed: D70.2 (A), K_70.1
unnamed: D71.2 (A), K_71.1
unnamed: D72.2 (A), K_72.1
unnamed: D73.2 (A), K_73.1
unnamed: D74.2 (A), K_74.1
unnamed: D75.2 (A), K_75.1
unnamed: D76.2 (A), K_76.1
unnamed: D77.2 (A), K_77.1, K_508A1.1
unnamed: D78.2 (A), K_78.1
unnamed: D79.2 (A), K_79.1, K_510A1.1
unnamed: D80.2 (A), K_80.1
unnamed: D81.2 (A), K_81.1
unnamed: D82.2 (A), K_82.1
unnamed: R1.2, SW1.2, U1.13 (~RESET)
unnamed: R2.2, U1.33 (~HWB~/PE2)
unnamed: R5.2, USB1.4 (CC1)
unnamed: R6.2, USB1.10 (CC2)
unnamed: U1.16 (XTAL2), Y1.3
unnamed: U1.17 (XTAL1), Y1.1
VCC: ESD1.4 (VCC), F1.2, USB1.2 (VBUS), USB1.11 (VBUS)
col0: K_1.2, K_14.2, K_29.2, K_44.2, K_59.2, K_73.2, K_300A1.2, U1.41 (PF0)
col1: K_2.2, K_15.2, K_30.2, K_45.2, K_60.2, K_74.2, U1.22 (PD5)
col2: K_3.2, K_16.2, K_31.2, K_46.2, K_61.2, K_75.2, U1.21 (PD3)
col3: K_4.2, K_17.2, K_32.2, K_47.2, K_62.2, U1.20 (PD2)
col4: K_5.2, K_18.2, K_33.2, K_48.2, K_63.2, U1.11 (PB3)
col5: K_6.2, K_19.2, K_34.2, K_49.2, K_64.2, U1.37 (PF6)
col6: K_7.2, K_20.2, K_35.2, K_50.2, K_65.2, K_76.2, U1.36 (PF7)
col7: K_8.2, K_21.2, K_36.2, K_51.2, K_66.2, U1.32 (PC7)
col8: K_9.2, K_22.2, K_37.2, K_52.2, K_67.2, K_77.2, K_508A1.2, U1.31 (PC6)
col9: K_10.2, K_23.2, K_38.2, K_53.2, K_68.2, K_78.2, U1.30 (PB6)
col10: K_11.2, K_24.2, K_39.2, K_54.2, K_69.2, K_79.2, K_510A1.2, U1.29 (PB5)
col11: K_12.2, K_25.2, K_40.2, K_55.2, K_70.2, K_80.2, U1.28 (PB4)
col12: K_13.2, K_26.2, K_41.2, K_56.2, K_71.2, K_81.2, U1.27 (PD7)
col13: K_27.2, K_42.2, K_57.2, K_113A1.2, U1.26 (PD6)
col14: K_28.2, K_43.2, K_58.2, K_72.2, K_82.2, U1.25 (PD4)
row0: D1.1 (K), D2.1 (K), D3.1 (K), D4.1 (K), D5.1 (K), D6.1 (K), D7.1 (K), D8.1 (K), D9.1 (K), D10.1 (K), D11.1 (K), D12.1 (K), D13.1 (K), U1.9 (PB1)
row1: D14.1 (K), D15.1 (K), D16.1 (K), D17.1 (K), D18.1 (K), D19.1 (K), D20.1 (K), D21.1 (K), D22.1 (K), D23.1 (K), D24.1 (K), D25.1 (K), D26.1 (K), D27.1 (K), D28.1 (K), U1.10 (PB2)
row2: D29.1 (K), D30.1 (K), D31.1 (K), D32.1 (K), D33.1 (K), D34.1 (K), D35.1 (K), D36.1 (K), D37.1 (K), D38.1 (K), D39.1 (K), D40.1 (K), D41.1 (K), D42.1 (K), D43.1 (K), U1.1 (PE6)
row3: D44.1 (K), D45.1 (K), D46.1 (K), D47.1 (K), D48.1 (K), D49.1 (K), D50.1 (K), D51.1 (K), D52.1 (K), D53.1 (K), D54.1 (K), D55.1 (K), D56.1 (K), D57.1 (K), D58.1 (K), U1.40 (PF1)
row4: D59.1 (K), D60.1 (K), D61.1 (K), D62.1 (K), D63.1 (K), D64.1 (K), D65.1 (K), D66.1 (K), D67.1 (K), D68.1 (K), D69.1 (K), D70.1 (K), D71.1 (K), D72.1 (K), U1.39 (PF4)
row5: D73.1 (K), D74.1 (K), D75.1 (K), D76.1 (K), D77.1 (K), D78.1 (K), D79.1 (K), D80.1 (K), D81.1 (K), D82.1 (K), U1.38 (PF5)

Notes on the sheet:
Decoupling Capacitors
ESD Protection
Microcontroller
USB C

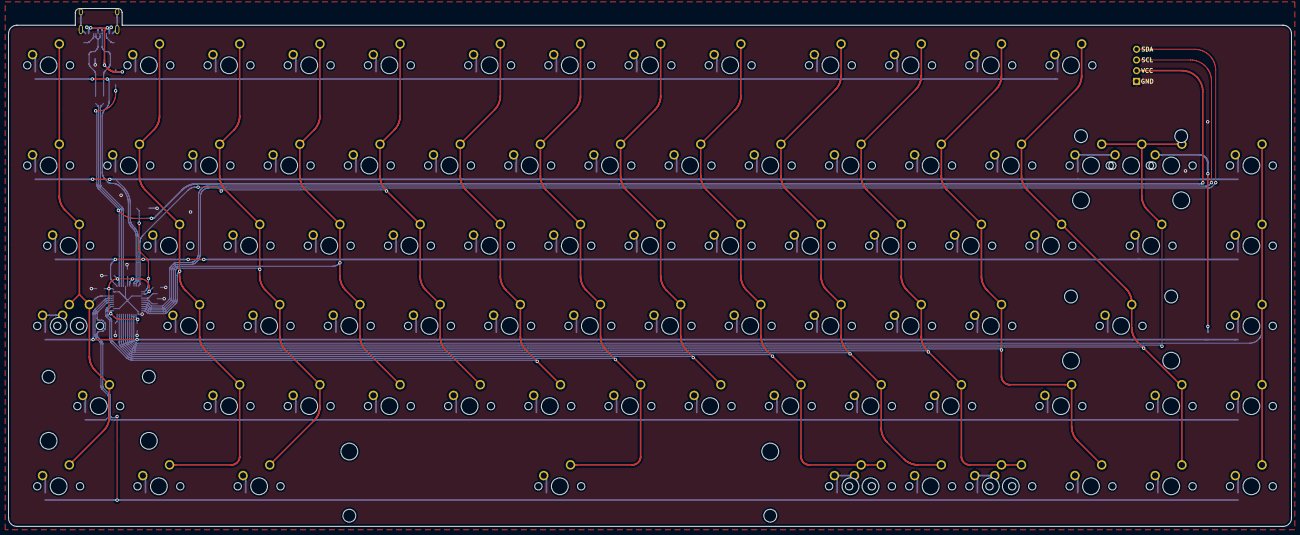
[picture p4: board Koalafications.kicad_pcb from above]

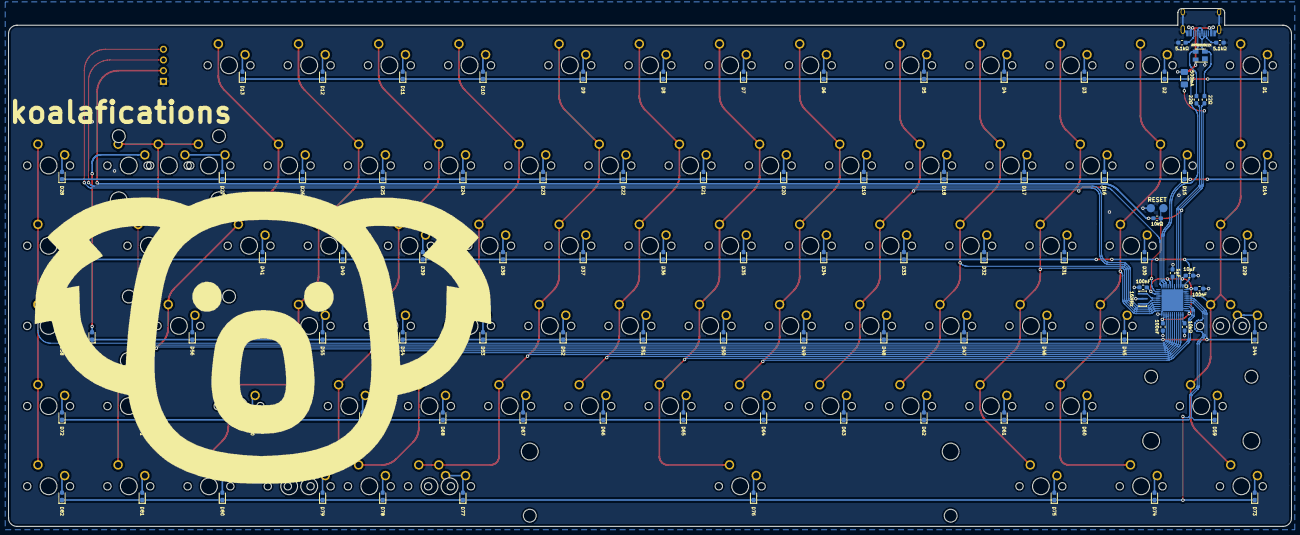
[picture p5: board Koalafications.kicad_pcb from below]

Board: 2 copper layers, 304.8 x 123.0 mm, 186 parts (99 on the bottom side), 119 nets.

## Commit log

2020-12-30 Init commit
    [Nodu-B_Cu.gbr, Nodu-B_Mask.gbr, Nodu-B_SilkS.gbr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]
2020-12-31 Layout Diodes
    [Seck_C_75.kicad_pcb]
2020-12-31 Layout Diodes + Route Cols
    [Seck_C_75.kicad_pcb]
2021-01-06 Make Gerbers + add Art
    [Koalafications-B_Cu.gbr, Koalafications-B_Mask.gbr, Koalafications-B_SilkS.gbr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]
